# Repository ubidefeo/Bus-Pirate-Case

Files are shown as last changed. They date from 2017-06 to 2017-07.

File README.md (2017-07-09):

# Bus Pirate Enclosure for BP v.4.0
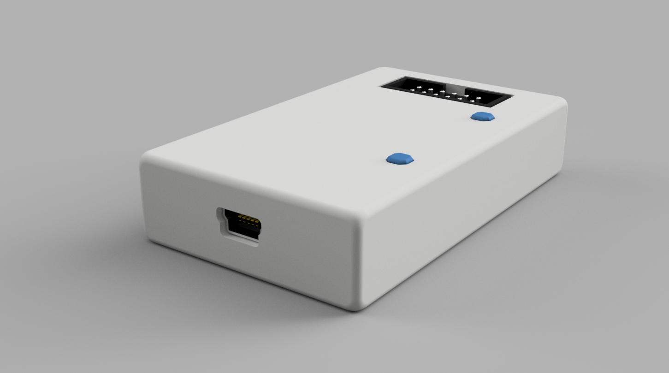
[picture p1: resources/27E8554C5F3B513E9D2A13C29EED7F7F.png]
Case v2


__NOTE:__ *I have modified the buttons to be round as the current shape had too small details to be printed correctly.
I'll upload new STL and models in the following days from my workstation (my laptop suffers).*

Designed in Fusion 360, starting with Eagle Board files downloaded from [Dangerous Prototype's GitHub repo](https://github.com/DangerousPrototypes/Bus_Pirate)

I have used the following process to create a 3d model of the v4.0 PCB:

* uploaded Eagle .brd file to [ECAD.io](http://ecad.io)
* carefully selected the components from the quite cumbersome UI of ECAD.io
* generated a STEP assembly
* opened the assembly in Autodesk Fusion 360
* saved it as a Fusion 360 model
* created a new document and added the PCB model to it
* designed the case around the model using projected shapes and boundaries
* the two parts are carefully designed with no over-hangs

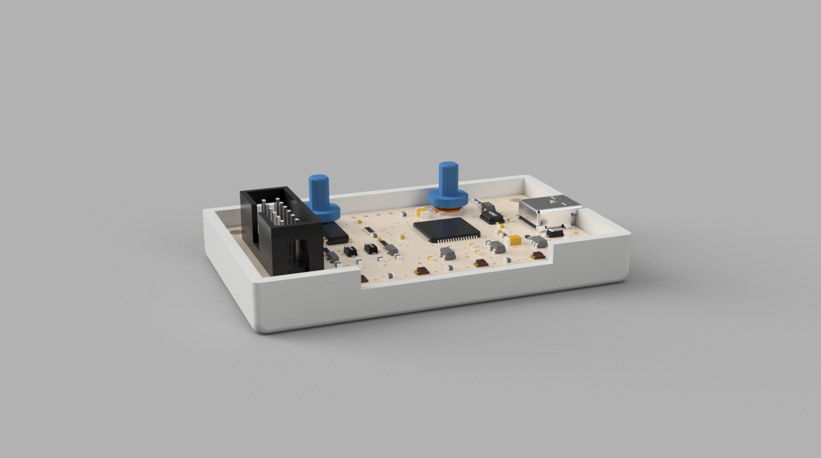
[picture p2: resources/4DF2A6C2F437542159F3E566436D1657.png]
Case - top off


__note__: these models have very tight tolerances in some areas and no tolerance at all in others.
This is possible because my Ultimaker is calibrated extremely well and I use an Olsson Block 0.4mm diameter.
I print at 0.06 layer height with layer 0 printed at 0.1.
An acetate sheet is glued to the build-plate glass to allow for easy removal of the parts (see [this video](https://www.youtube.com/watch?v=MMxrqxx-Fjg) on my YT channel)
I only use [Rigid.ink PLA](http://rigid.ink) because of its quality and strength.
Models are printed one at a time.

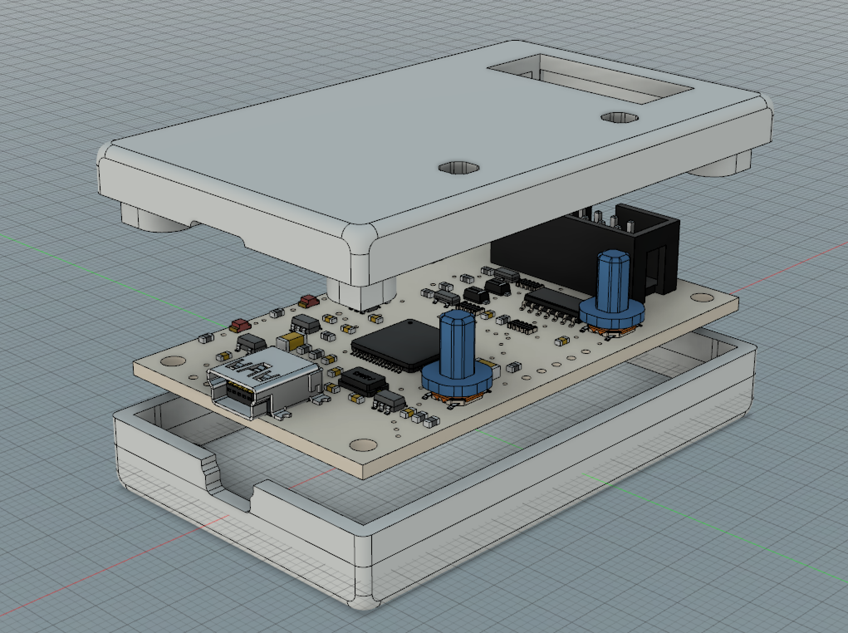
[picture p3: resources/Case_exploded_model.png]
Explode


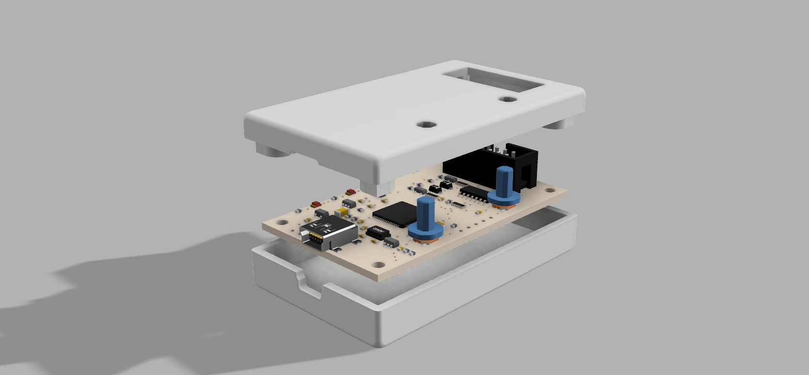
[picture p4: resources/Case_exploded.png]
Explode


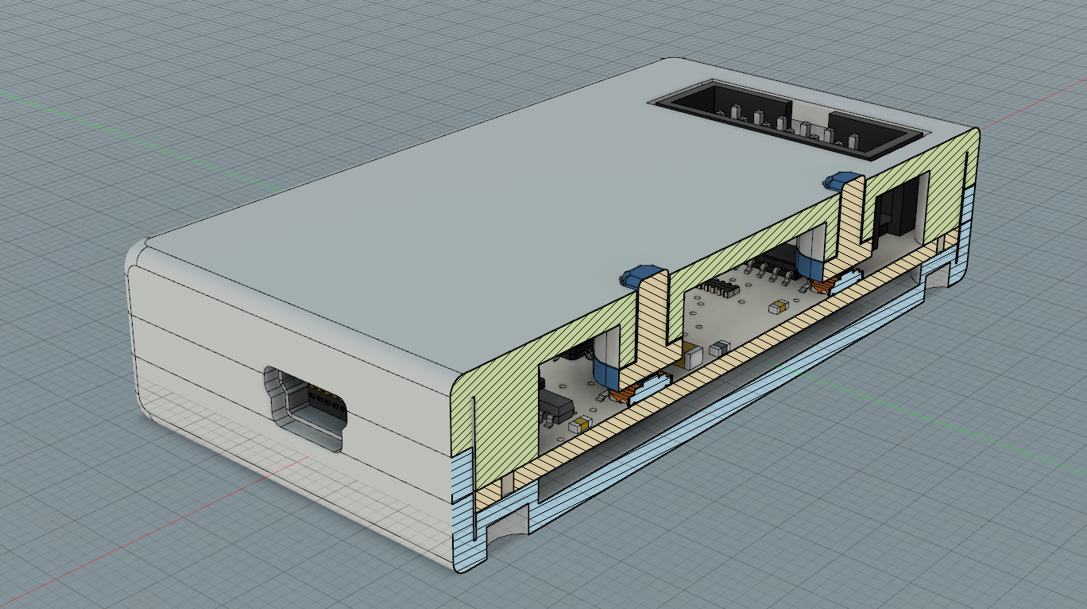
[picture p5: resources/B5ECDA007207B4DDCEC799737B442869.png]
Section


The model is made in 2 main parts (bottom and top) plus the buttons.
I have created a Simplify3D factory file with settings for my Ultimaker 2 printer.

### downloads
#### STL
* [Bottom](models-STL/Bottom.STL)
* [Top](models-STL/Top.STL)
* [Buttons](models-STL/Buttons.STL)

#### Fusion 360 (.F3D)
* [Assembly](models-Fusion360/BusPirate_v4.0_Case.f3d)

#### Simplify3D
* [Factory File (all parts)](Simplify3D/BusPirate_ALL.factory)

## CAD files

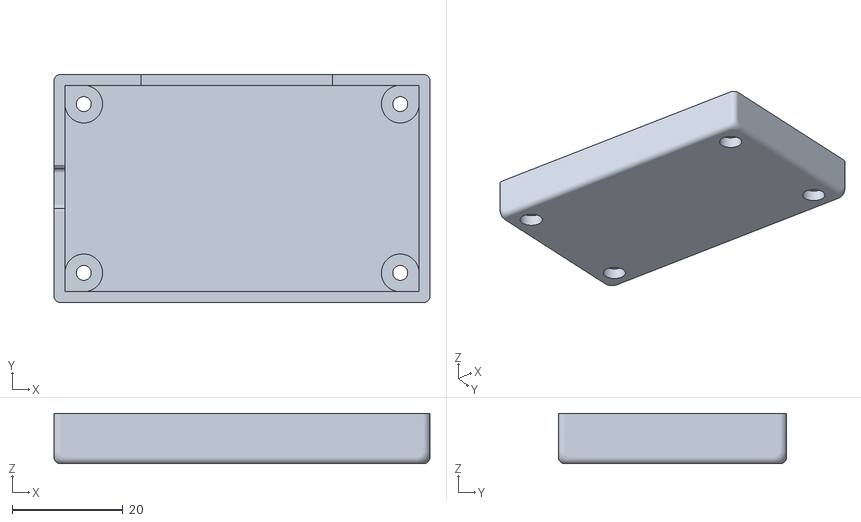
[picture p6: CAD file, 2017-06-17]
models-STL/Bottom.stl
67.9 x 41.2 x 9.11

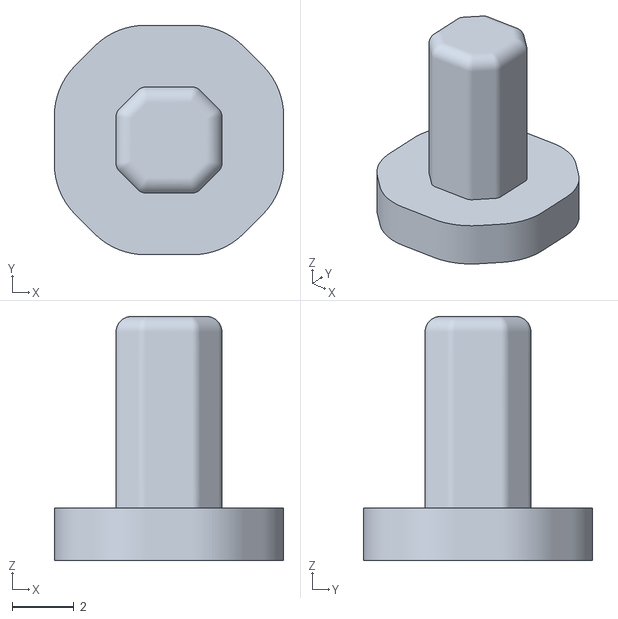
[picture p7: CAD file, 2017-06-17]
models-STL/Button.stl
7.43 x 7.43 x 7.90

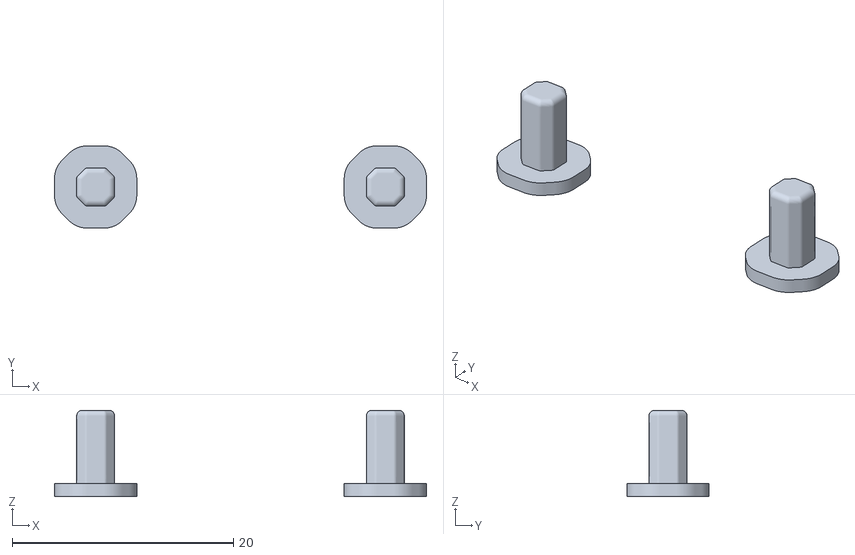
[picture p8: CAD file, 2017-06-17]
models-STL/Buttons.stl
33.6 x 7.43 x 7.80

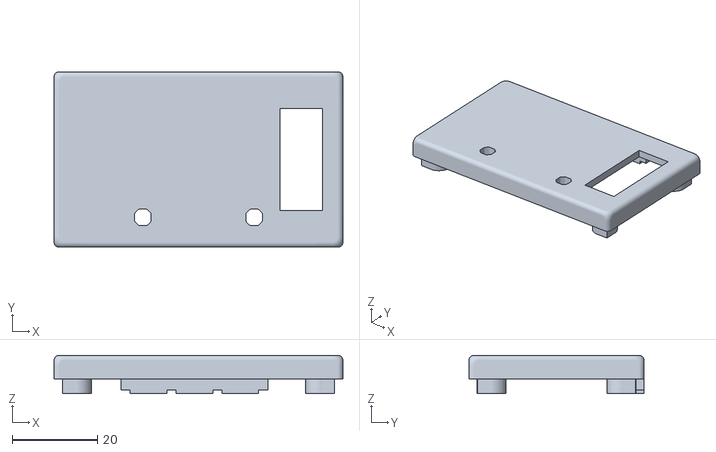
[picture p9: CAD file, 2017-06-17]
models-STL/Top.stl
67.9 x 41.2 x 9.00

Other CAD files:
models-Fusion360/BusPirate_v4.0_Case.f3d
models-Fusion360/BusPirate_v4.1_Case.f3d

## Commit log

2017-06-17 updated resources
    [BusPirate_v4.0_Case.f3d]
2018-08-27 - updated buttons shape for ease of print on my UM2, although I have refined settings and v4.0 might still be a better version
    [BusPirate_v4.1_Case.f3d]
